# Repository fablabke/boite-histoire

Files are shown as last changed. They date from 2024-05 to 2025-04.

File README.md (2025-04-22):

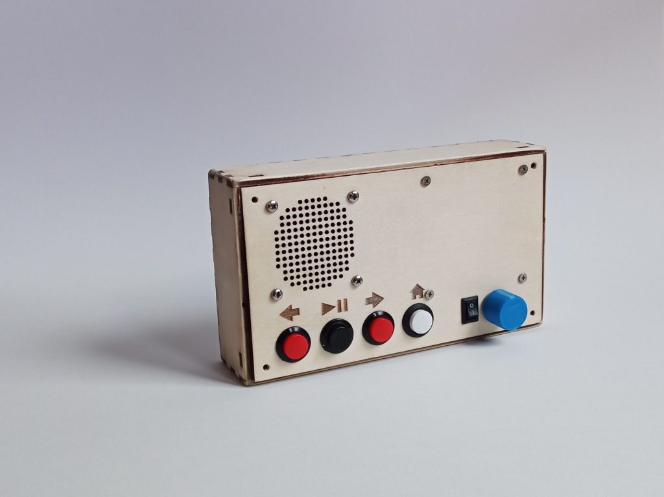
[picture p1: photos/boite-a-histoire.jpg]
Une boite à histoire open hardware


## Boite à histoire

Une boite à histoire complètement open source et open hardware, un projet du Fablab'ke.

Il existe sur le marché une série de “boîtes à histoires” qui permettent aux enfants d’écouter des histoires en audio. C’est un système qui fonctionne très bien et permet d’éviter les écrans tout en découvrant des univers assez variés. Écouter des histoires permet aussi de développer le langage et l’imaginaire.

Il y a par exemple la [boîte Lunii](https://lunii.com/fr-be/) et [pleins d’autres modèles](https://www.madmoizelle.com/quelles-sont-les-meilleures-boites-a-histoires-pour-les-enfants-1392363)

L’inconvénient majeur de toutes ces boîtes est le coût élevé de l’appareil (entre 70 et 100 euros) et le coût des packs d’histoires (une dizaine d’euros à chaque fois que l’on veut ajouter quelques histoires sur sa boîte sans pouvoir les partager avec d’autres).

Un autre inconvénient est que les bibliothèques d’histoires sont spécifiques à chaque fabricant, avec un contenu souvent assez lisse et peu multiculturel.

Nous avons décidé au Fablab'ke de développer et de fabriquer “notre” boîte à histoire maison, de créer en partenariat avec les autres cellules de la maison des cultures plusieurs projets autour de celle-ci, et d’en faire bénéficier les familles de la maison des cultures et au-delà.

Cette boite à histoire permet d'y installer autant d'histoire qu'on le souhaite, sans devoir passer par un "app-store" et permet du coup d'inventer et de se partager des histoires entre participant.e.s.

Une première série de 30 boites à histoire a été construite avec les classes d'informatique de Campus Saint Jean.

Ce projet est en cours de conception. [Contactez le fablab'ke](https://fablabke.be) pour plus d'informations.

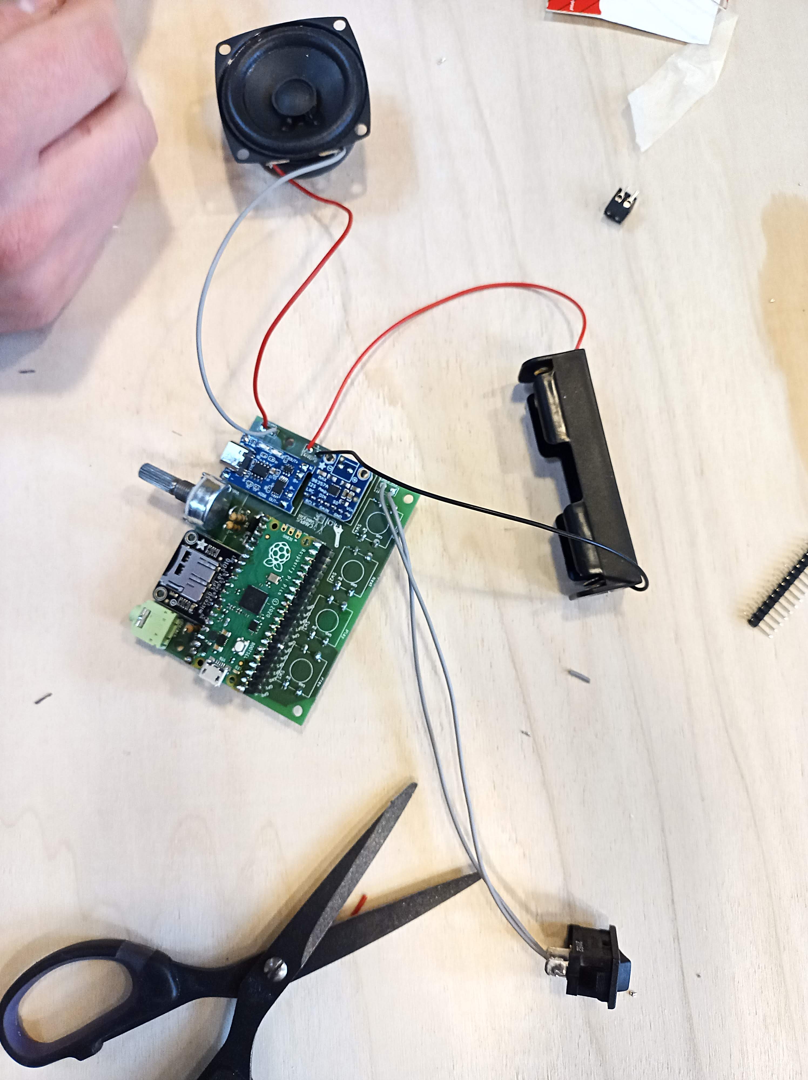
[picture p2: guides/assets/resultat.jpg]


## Mais comment fabriquer sa boite à histoire?

Lisez les documents suivants afin de comprendre les différentes étapes de fabrication et comment fabriquer la vôtre : 

- Principe de fonctionnement (todo)
- Carte électronique chez Aisler (todo)
- [Assemblage de la carte électronique](./guides/pcb.md)
- Code source arduino, facilement compilable avec platformio ou l'ide arduino : [/dossier arduino](./arduino)
- Code circuitpython (todo)

## Liste des composants nécessaires
- une plaquette d'expérimentation ou le circuit imprimé que l'on peut commander en ligne chez aisler.
- carte raspberry pi pico
- carte ampli i2s adafruit https://www.adafruit.com/product/3006 (clone : https://www.aliexpress.com/item/1005005985389931.html )
- carte chargeur (si vous voulez connecter une batterie) https://www.aliexpress.com/item/1005005982385924.html
- carte breakout sd adafruit : https://www.adafruit.com/product/4682
- potentiometre à souder trough hole 10k (par exemple : https://www.mouser.fr/ProductDetail/Same-Sky/PTN16-A10220K1B1?qs=VJzv269c%252BPbZP2voFoR5Tw%3D%3D )
- prise jack pour casque de ce type : https://www.mouser.be/ProductDetail/Same-Sky/SJ1-3525NG-GR?qs=WyjlAZoYn51BeLQaUbXH3w%3D%3D
- 3 résistances de 100k

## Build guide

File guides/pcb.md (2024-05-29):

# Assemblage de la boite à histoire

Matériel nécessaire :

- fer à souder
- soudure
- pince à dénuder
- pince coupante
- des ciseaux
- du scotch de peintre

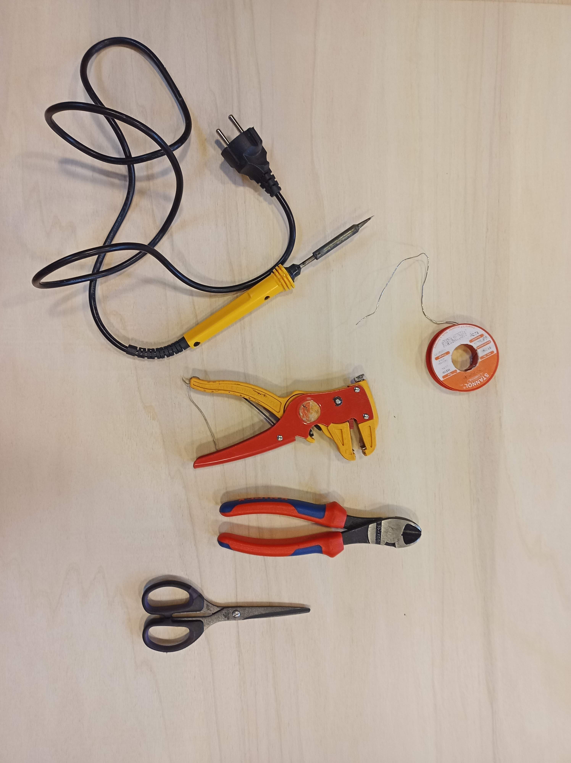
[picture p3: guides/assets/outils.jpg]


On commence par les composants passifs (diodes et résistances)

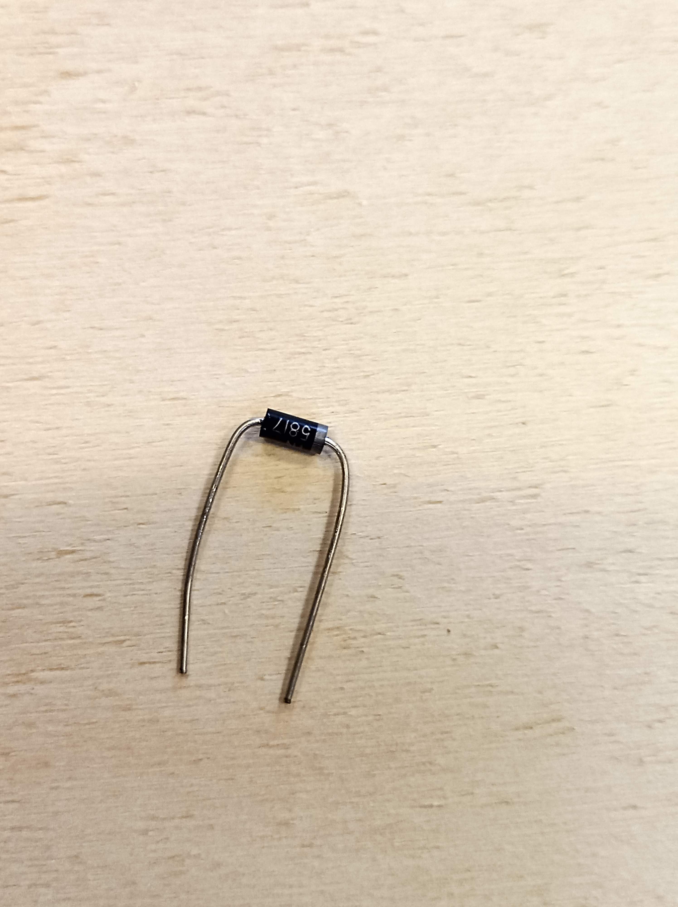
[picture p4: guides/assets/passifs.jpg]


Plier les pates de résistances et des diodes :

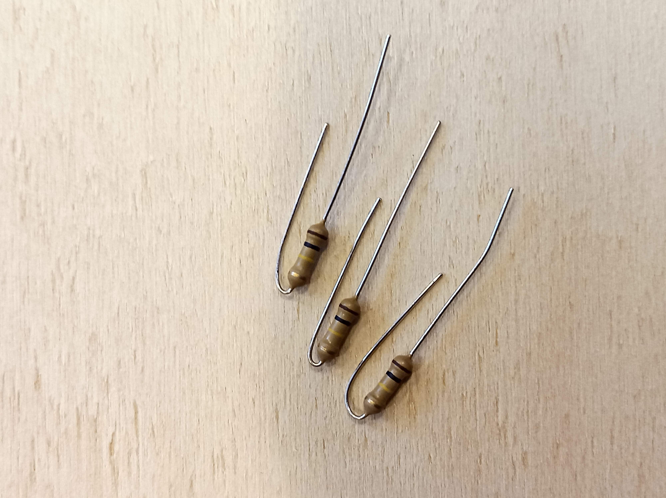
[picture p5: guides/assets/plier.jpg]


Placer la diode et les résistances sur le circuit imprimé (PCB). On peut plier les pates pour que les composants ne bougent pas.

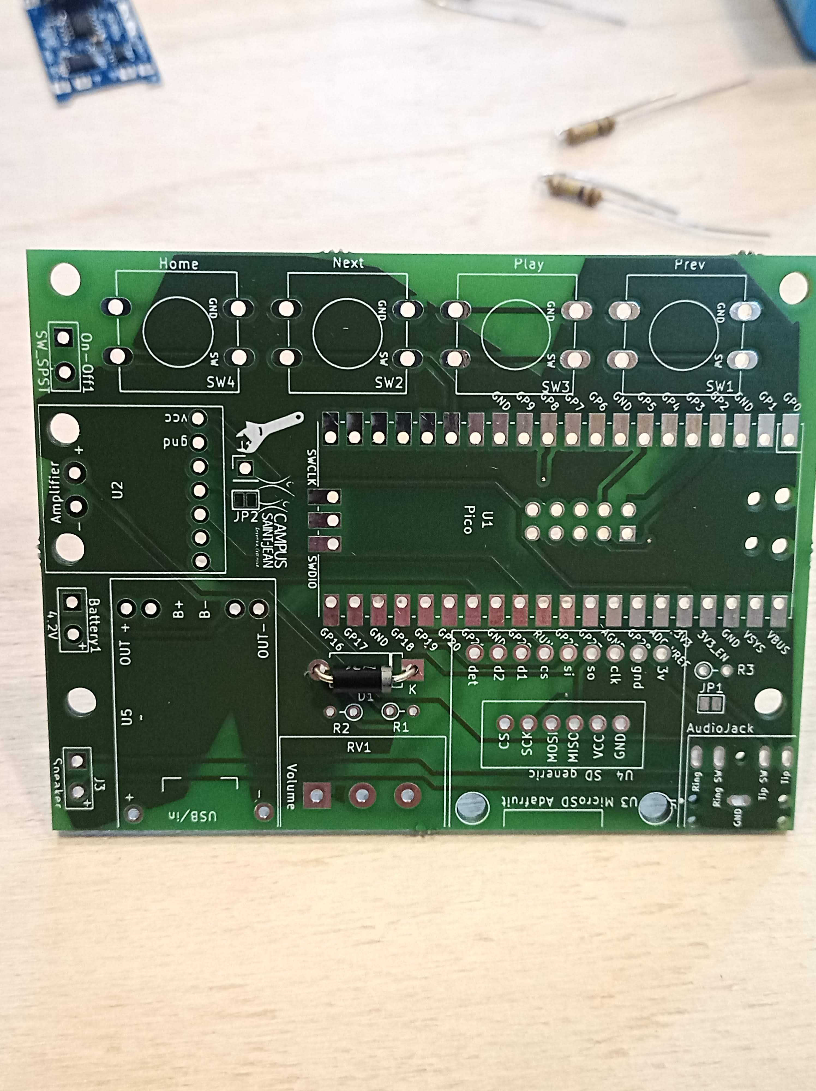
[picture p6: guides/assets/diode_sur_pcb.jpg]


Souder les pates :
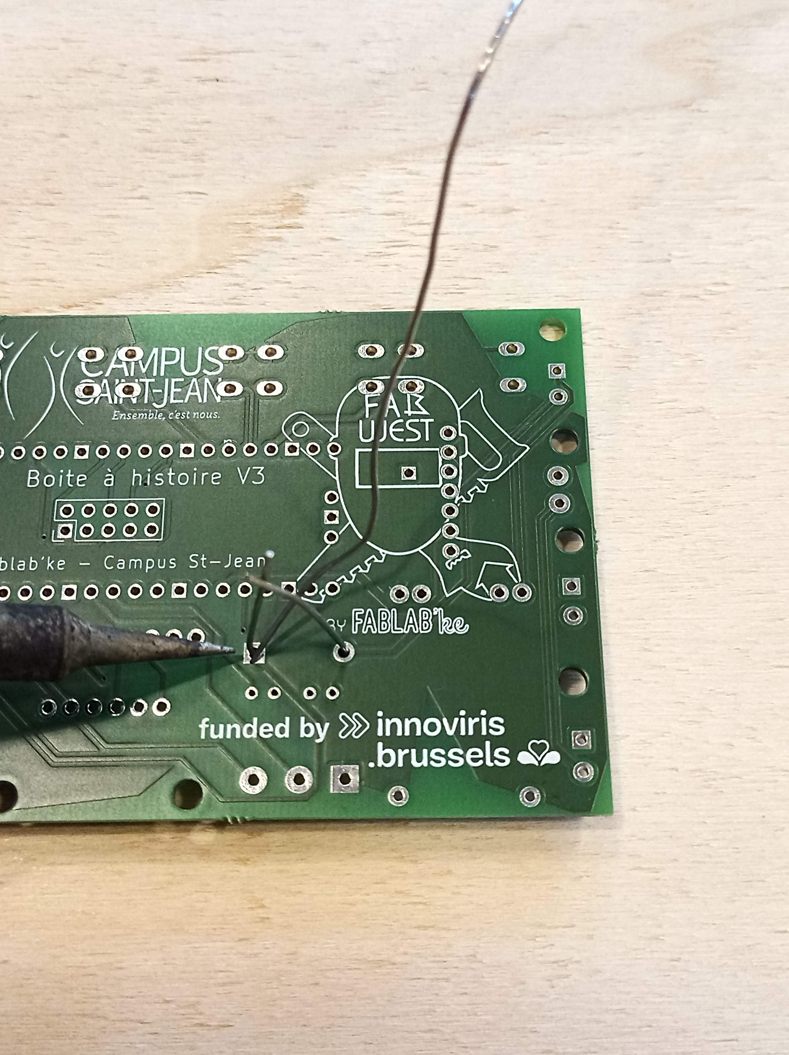
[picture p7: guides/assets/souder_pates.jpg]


On passe au lecteur de cartes SD : 
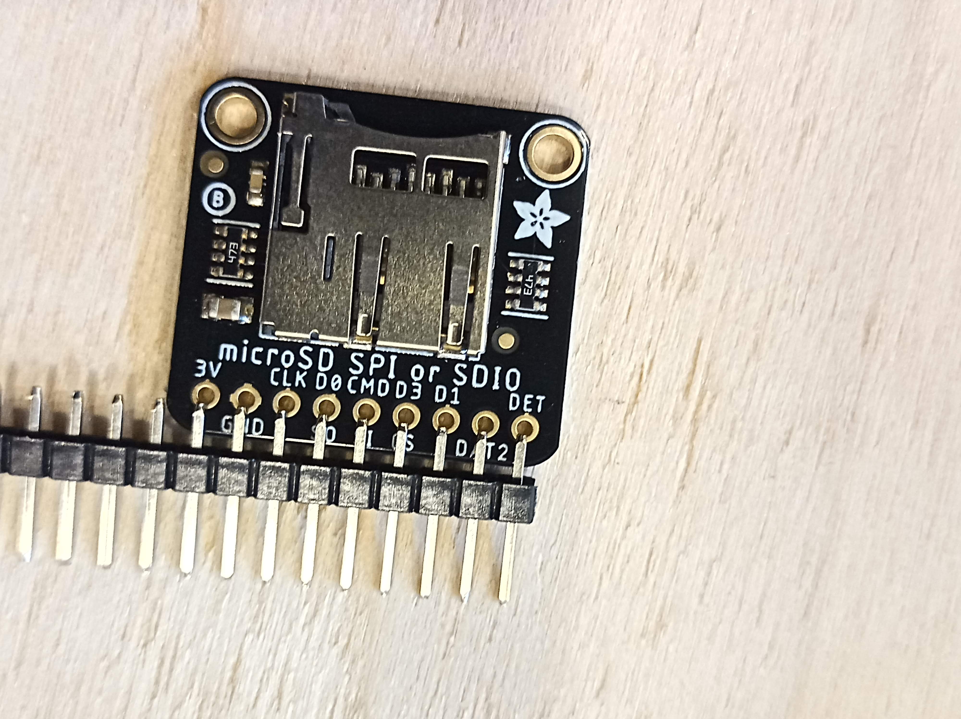
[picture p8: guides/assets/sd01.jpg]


Découper la barette de pins à la bonne longueur :
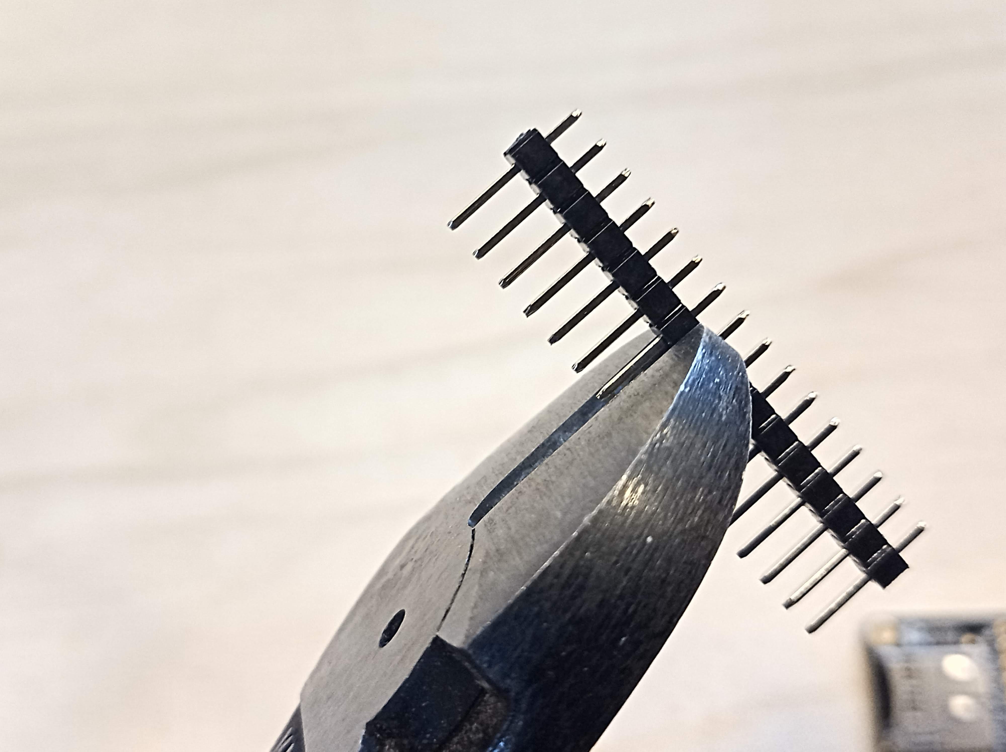
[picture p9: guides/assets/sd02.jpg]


Assembler le lecteur de carte et la barette. Placer le tout sur le circuit imprimé.
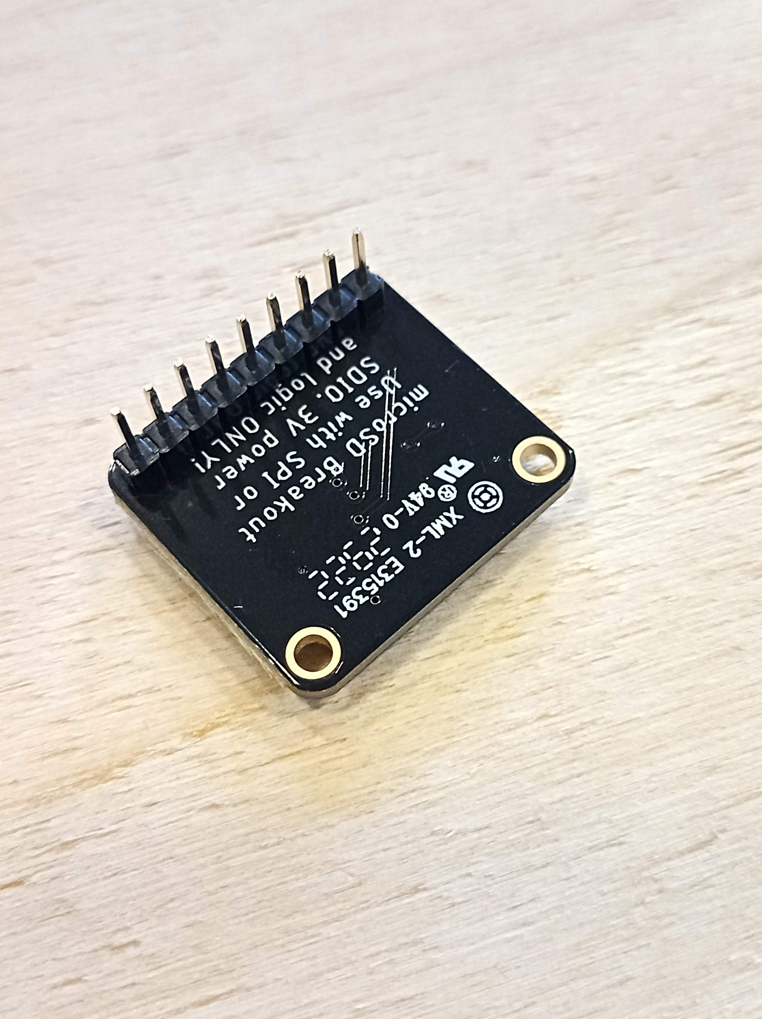
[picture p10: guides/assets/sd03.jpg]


Attention à garder le lecteur de carte SD bien droit, bien parallèle au circuit imprimé. On peut s'aider d'une ptite calle avant de souder.
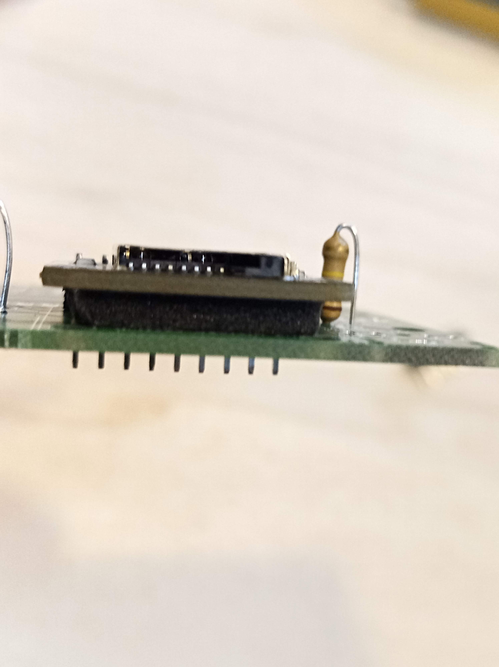
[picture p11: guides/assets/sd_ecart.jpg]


Souder les broches côté lecteur de carte SD et ensuite à l'arrière du circuit imprimé
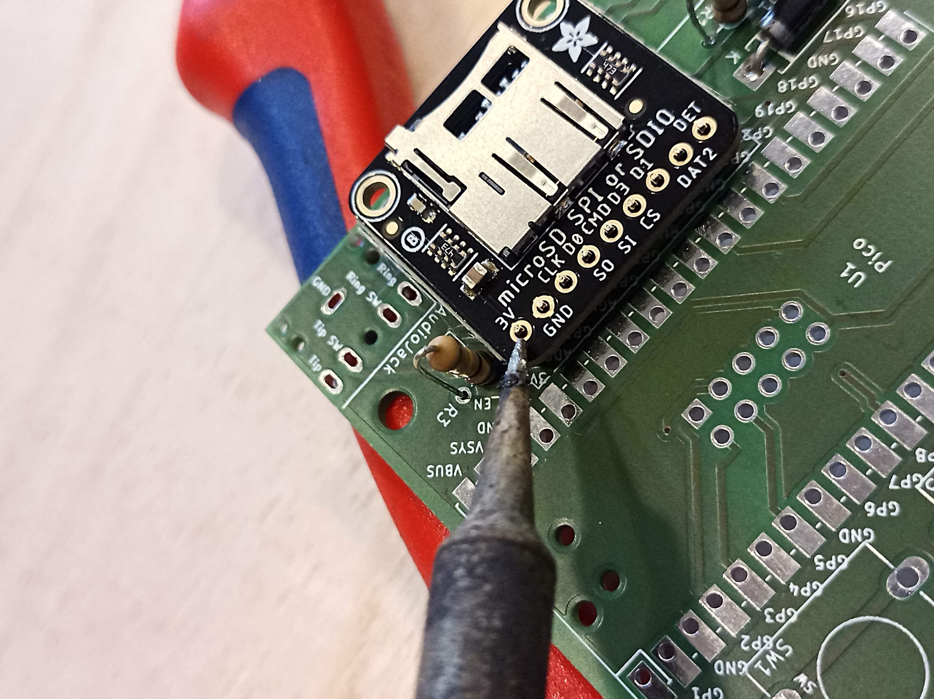
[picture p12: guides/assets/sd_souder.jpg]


On continue avec la carte son, couper les broches nécessaires :
- 1x 7 broches
- 2x 1 broche

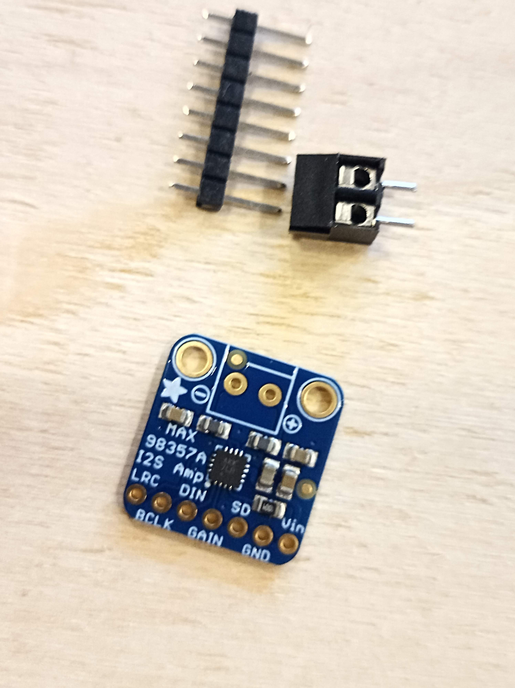
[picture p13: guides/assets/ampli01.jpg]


Ensuite mettre les broches à l'arrière de la carte ampli et insérer le tout sur le PCB
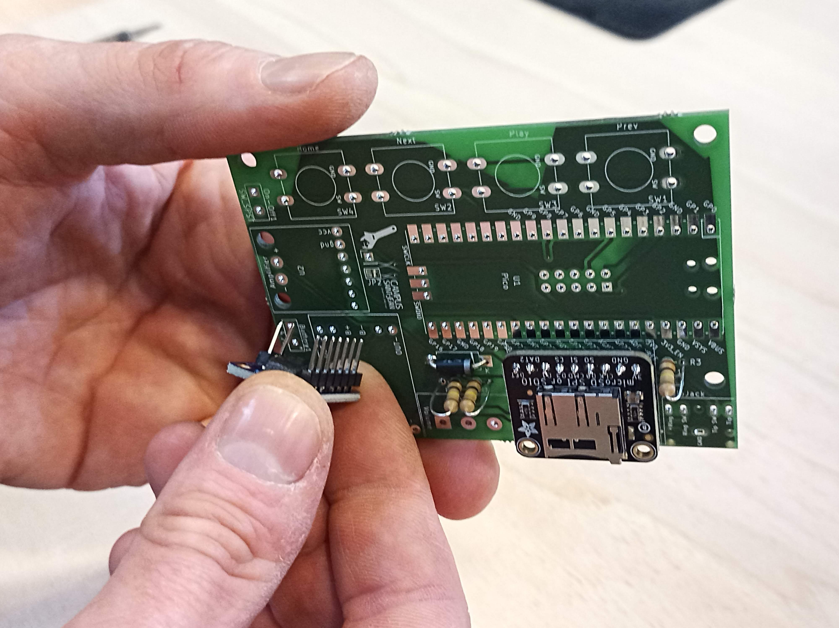
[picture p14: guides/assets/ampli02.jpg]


Un morcau de scotch permet de maintenir la carte avant de la souder :
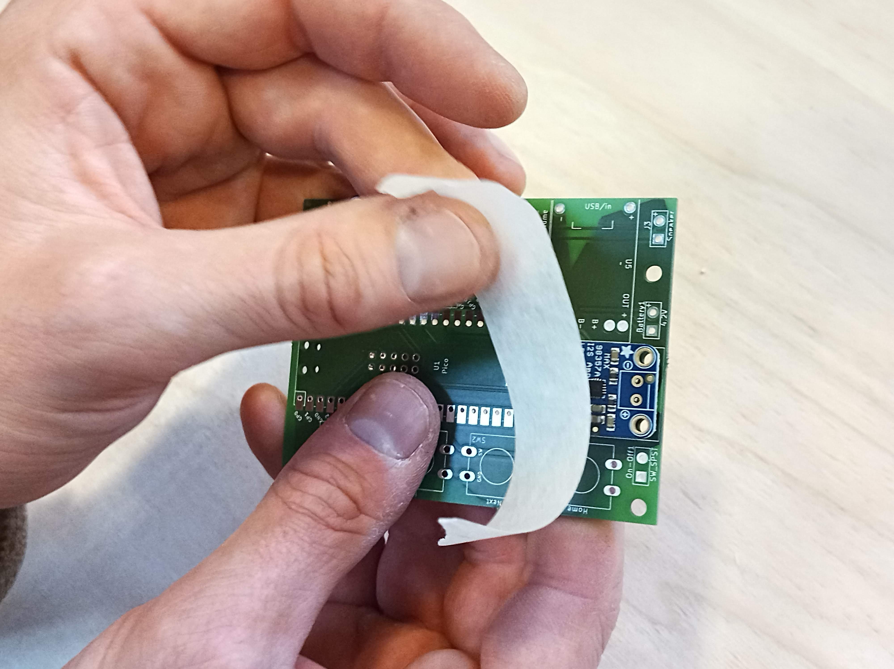
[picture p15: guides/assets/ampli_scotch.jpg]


On continue avec le chargeur, il faut couper 2x 2 pins et 2x 1 pin, tout mettre sur la PCB et ensuite positionner le chargeur sur les pins et souder le tout. 
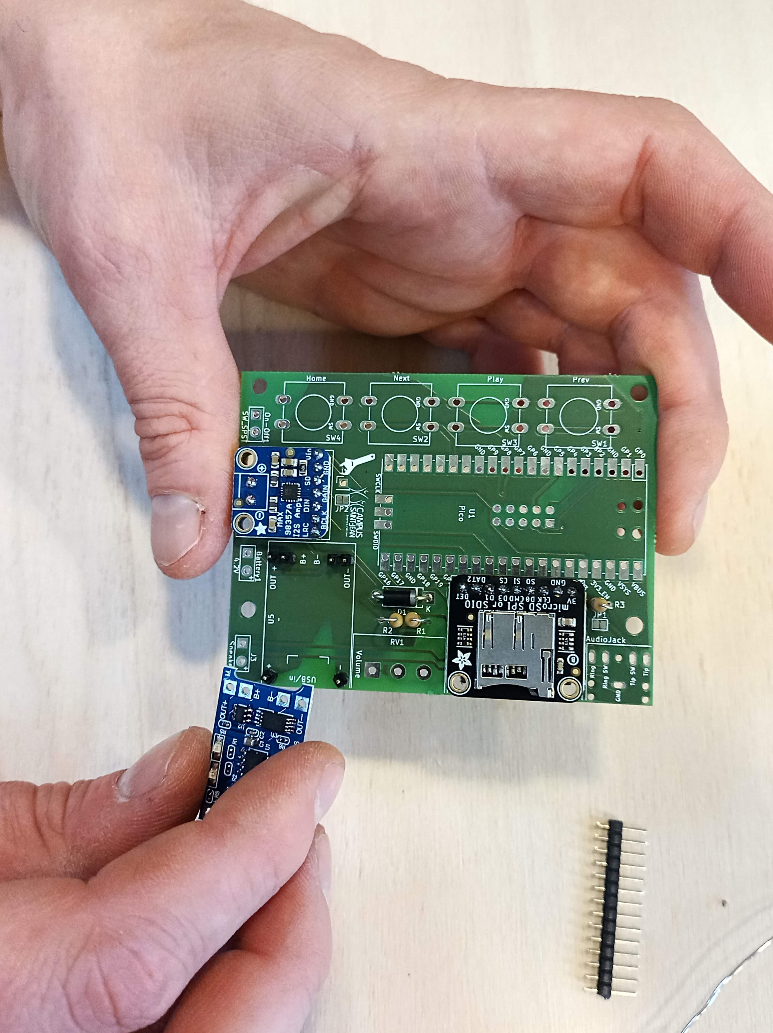
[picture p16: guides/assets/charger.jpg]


Veillez a bien garder le chargeur parallèlle au PCB
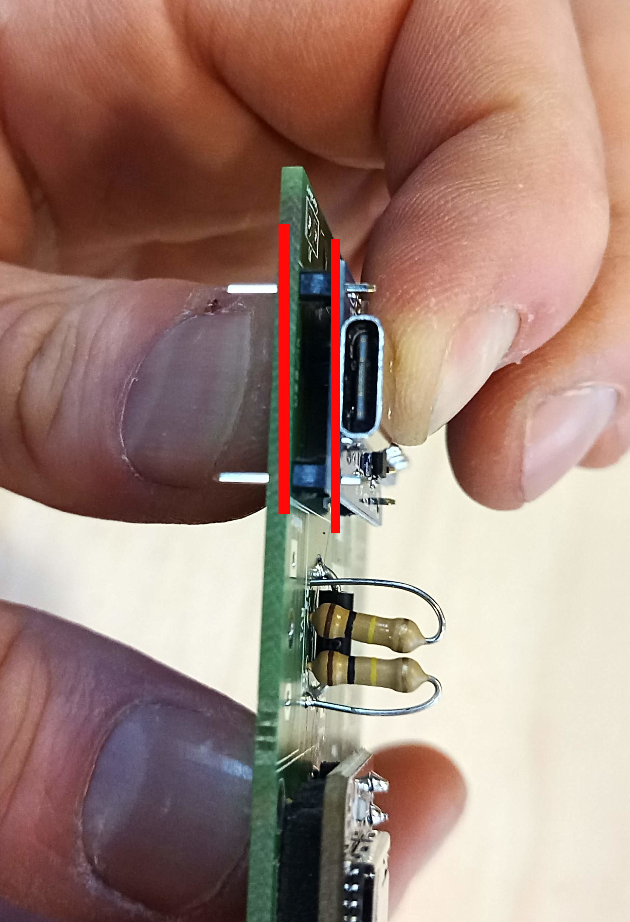
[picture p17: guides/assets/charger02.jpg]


Un sctoch est de nouveau bien pratique pour maintenir le tout.
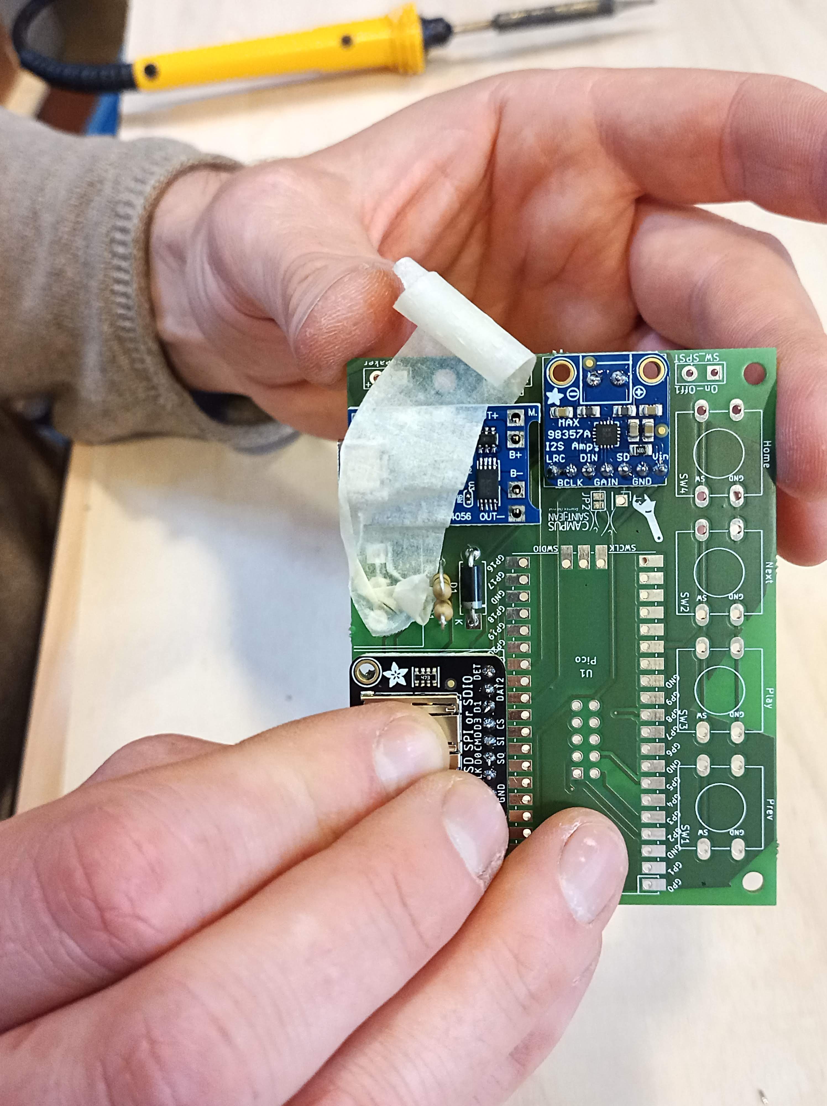
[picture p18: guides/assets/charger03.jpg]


Prendre la pico et enfoncer le "header" sur ses broches :
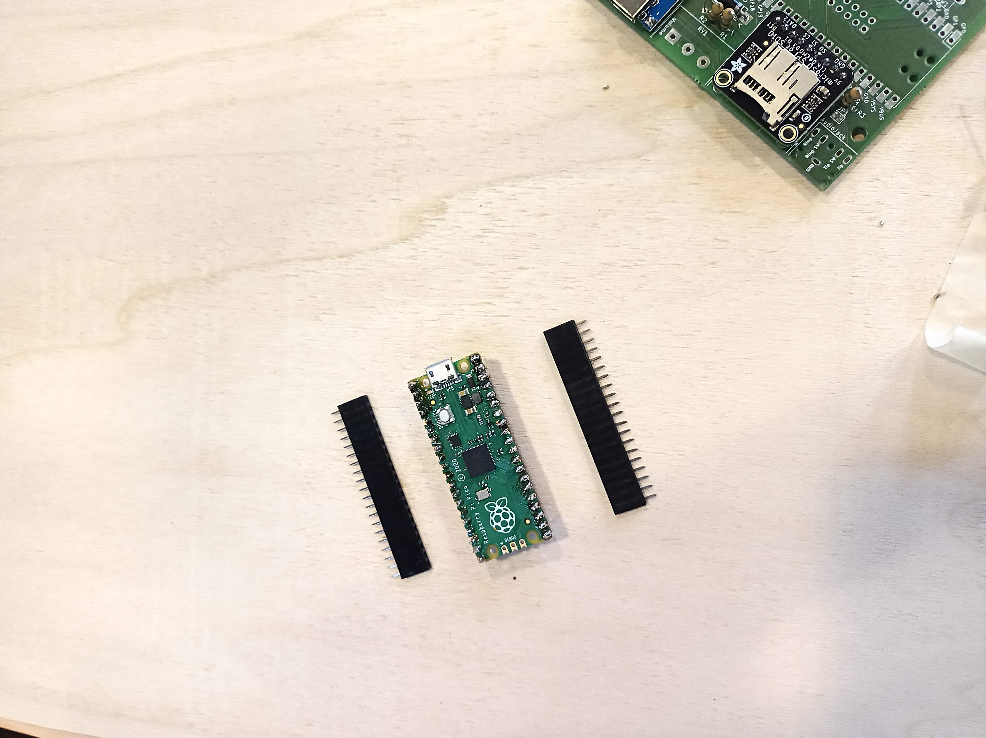
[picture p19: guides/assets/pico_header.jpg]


Placer la carte pico avec ces header et souder les broches
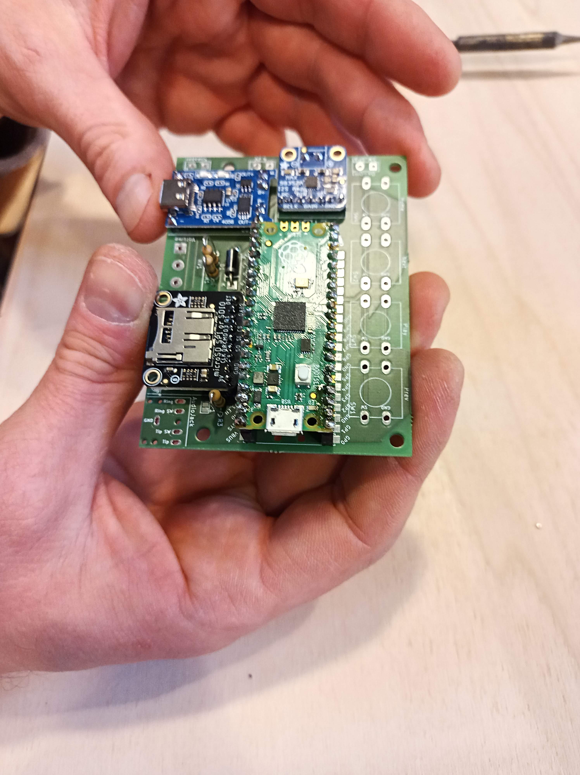
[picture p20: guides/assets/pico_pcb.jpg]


Encore une fois, le scotch permet de tout bien maintenir :-)
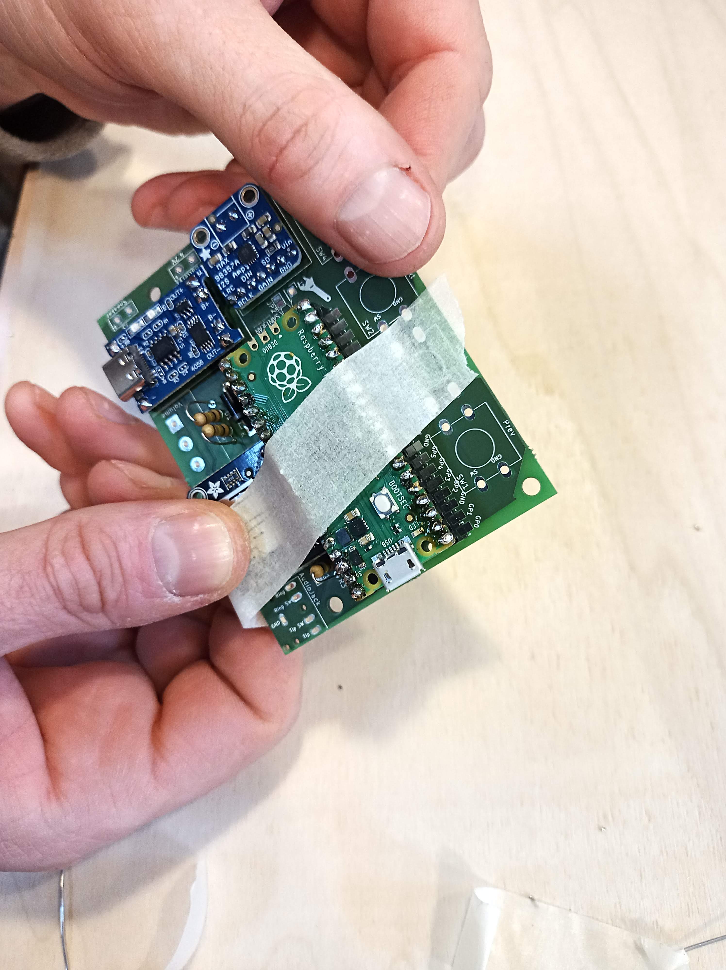
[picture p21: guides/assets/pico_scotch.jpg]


Souder chaque broche en faisant attention à ne pas créer de pont entre deux soudures
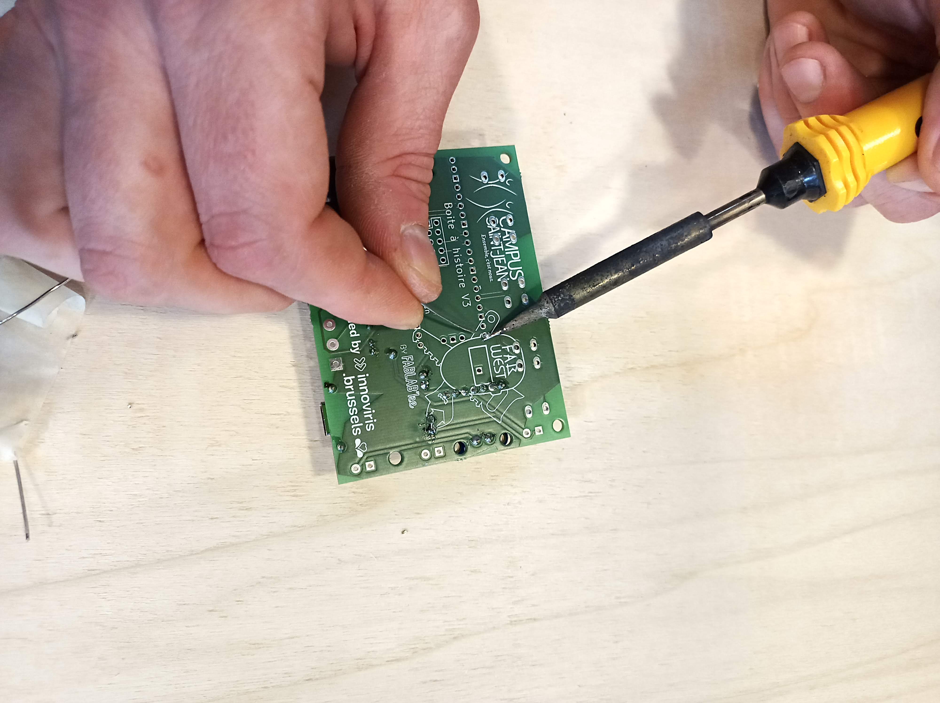
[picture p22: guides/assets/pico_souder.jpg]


On passe aux switches, soit souder le switches directement sur la pcb, soit souder des fils de cablage pour avoir des switchs déportés sur le boitier
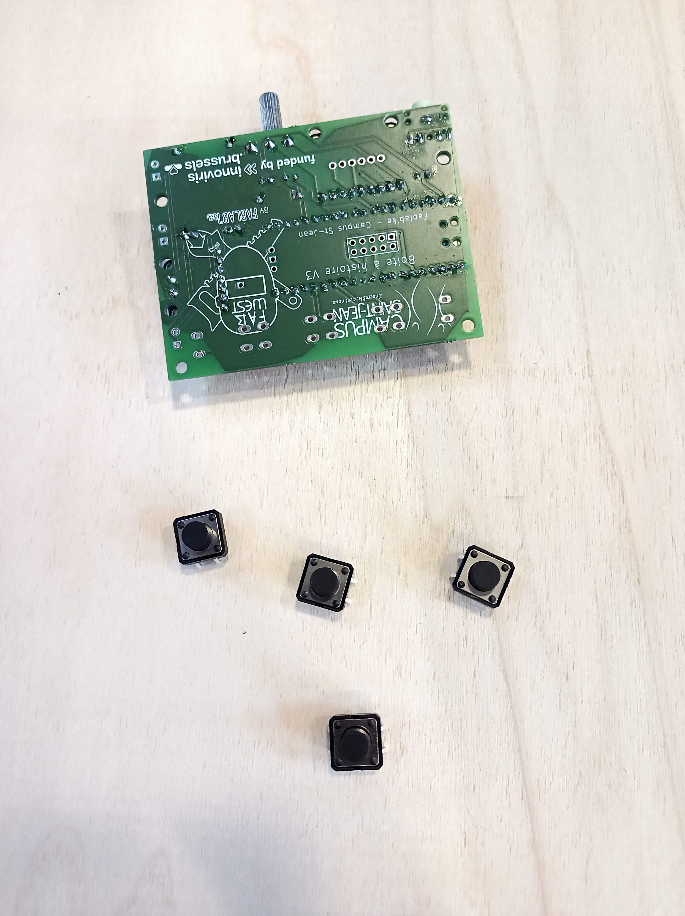
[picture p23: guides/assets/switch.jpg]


Exemple ici avec les switch soudés à l'arrière de la PCB. La carte sera vissée directement au boitier afin que les switches soient visibles.
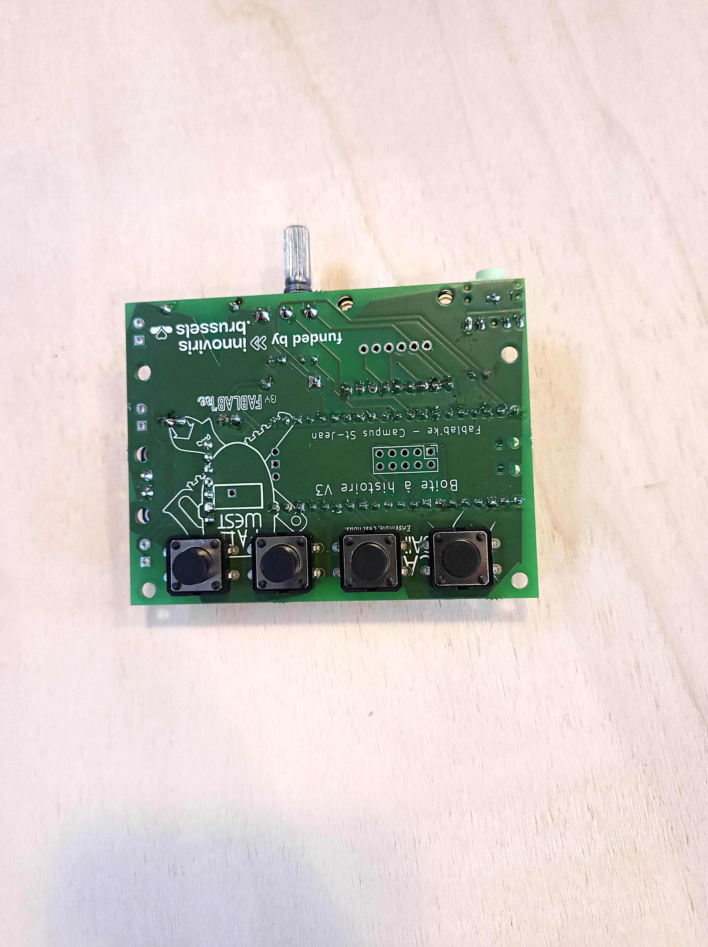
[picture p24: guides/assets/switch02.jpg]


Souder le potentiomètre directement sur la PCB
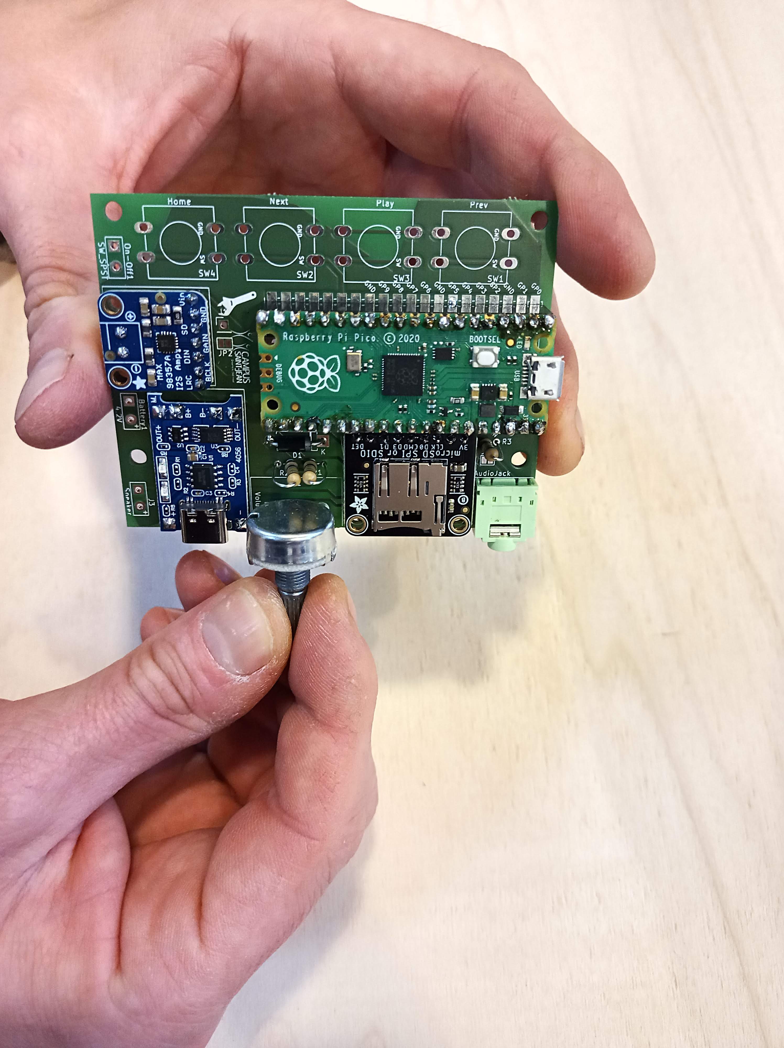
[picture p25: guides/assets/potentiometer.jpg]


Terminer par souder du fil de cablage sur les pads "switch", "speaker", en s'aidant d'un scotch
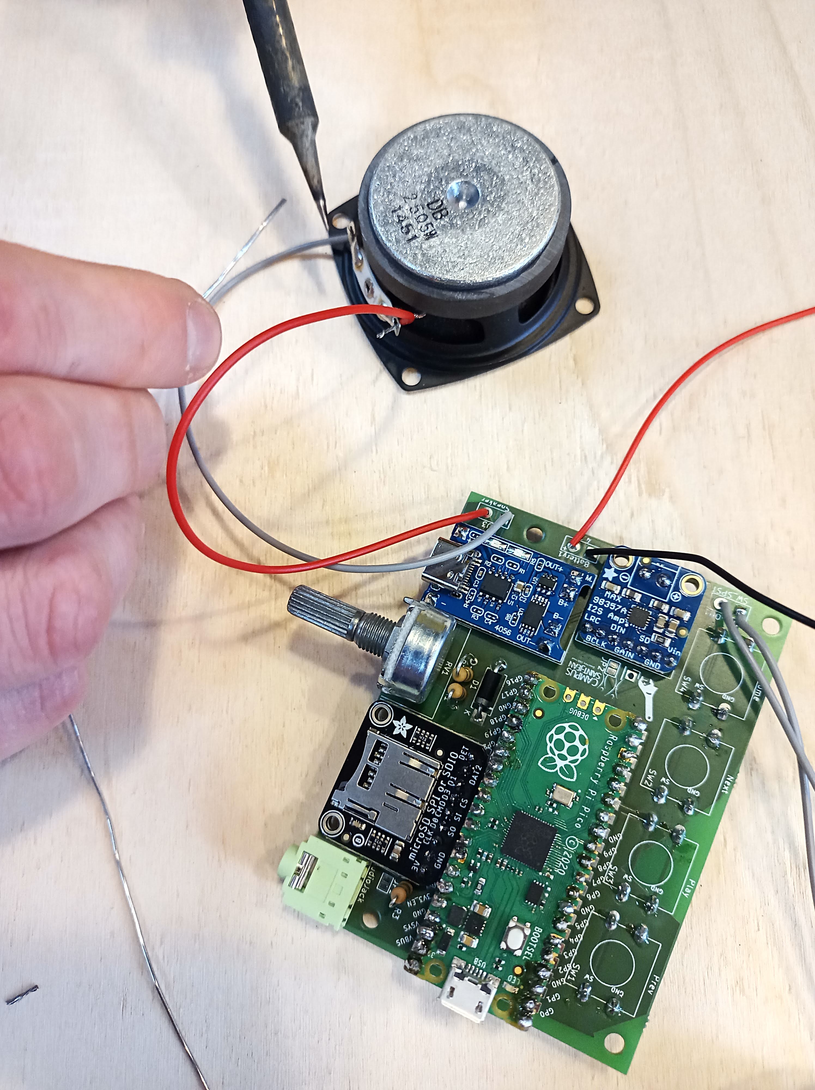
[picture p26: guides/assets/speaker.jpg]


Et voilà, tout est soudé :






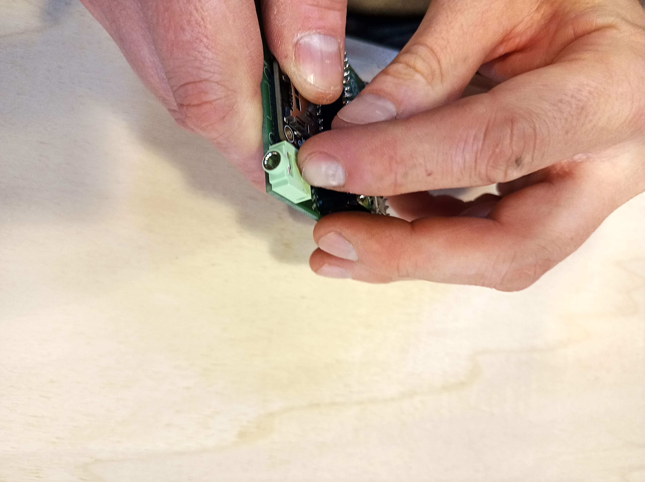
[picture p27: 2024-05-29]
guides/assets/jack.jpg

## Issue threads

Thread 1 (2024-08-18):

Schémas électriques

nonobike, 2024-08-18:
Bonjour,

D'abord merci beaucoup pour votre travail qu'il est remarquable.

Avez vous le schéma de cablage complet du projet ?

Je n'ai rien trouvé dans le github

Merci

Arnaud

philippejadin, 2024-08-19:
Merci!
Je viens d'ajouter le shéma en version pdf ici : https://github.com/fablabke/boite-histoire/blob/main/pcb/storybox.pdf

Si vous installez kicad, vous pourrez voir le schemé ainsi que la PCB.

philippejadin, 2024-08-19:
Et ça nous fera super plaisir d'avoir des retours, ici ou par mail :-)
Je compte encore travailler à ce projet afin de le rendre fabriquable par d'autres sans trop de difficultés.

brunodeprez, 2025-01-03:
Super interessé par ce projet !

philippejadin, 2025-01-03:
N'hésitez si vous avez des questions. Je dois encore un peu retravailler le firmware mais à part ça le projet est très fonctionnel

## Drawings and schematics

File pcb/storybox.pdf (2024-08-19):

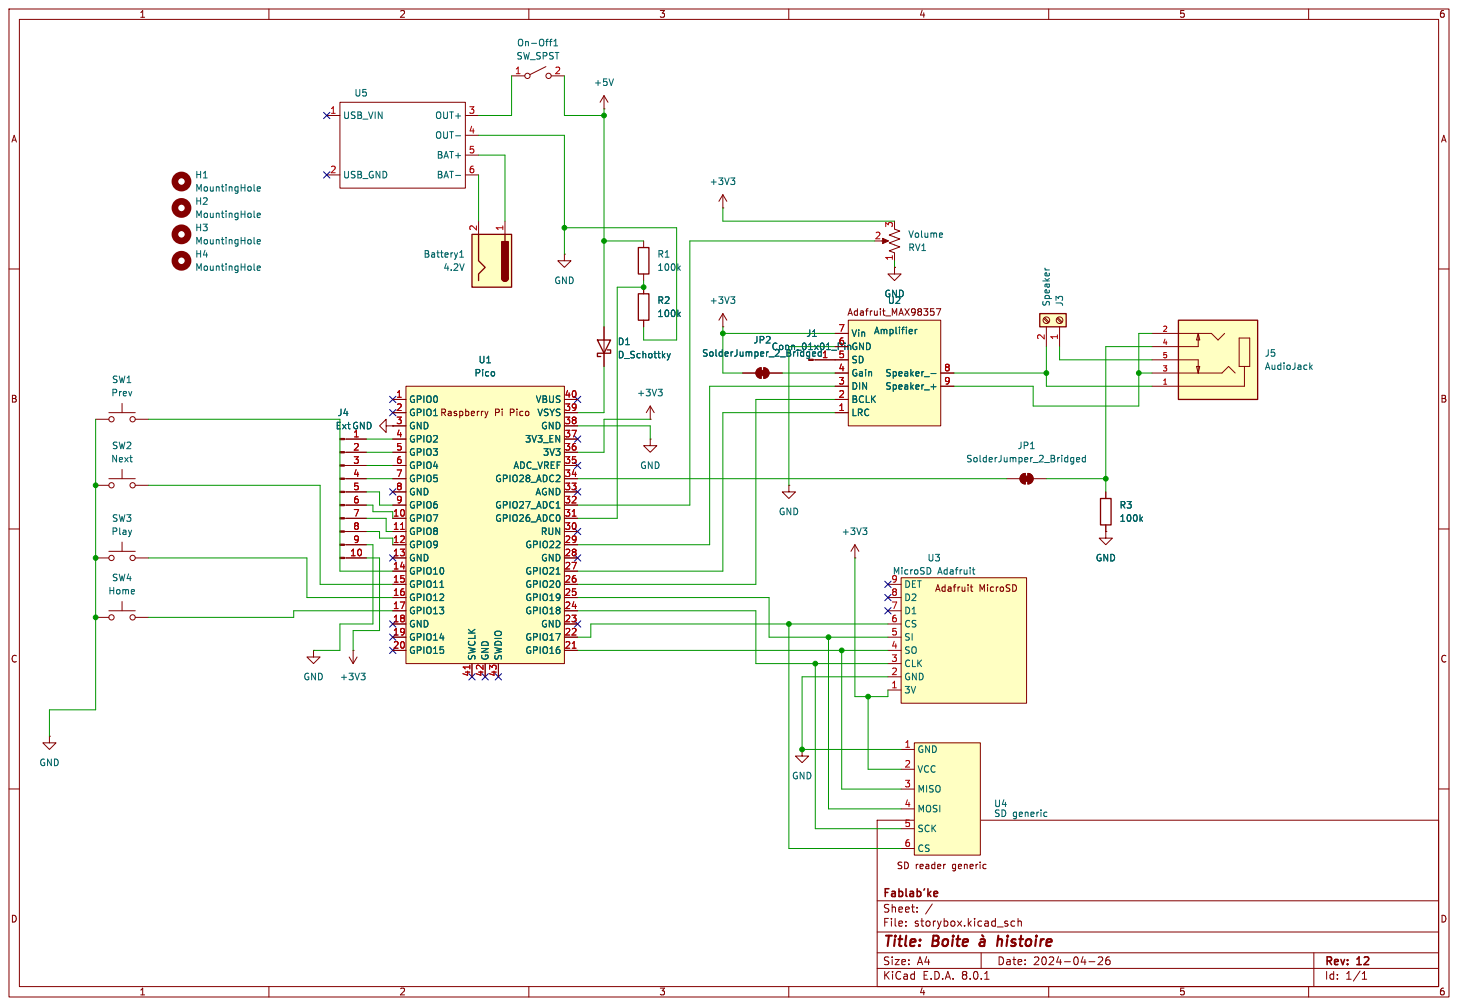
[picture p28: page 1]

File: storybox.kicad_sch Sheet: / Fablab'ke GND

Id: 1/1 Title: Boite þÿàhistoire

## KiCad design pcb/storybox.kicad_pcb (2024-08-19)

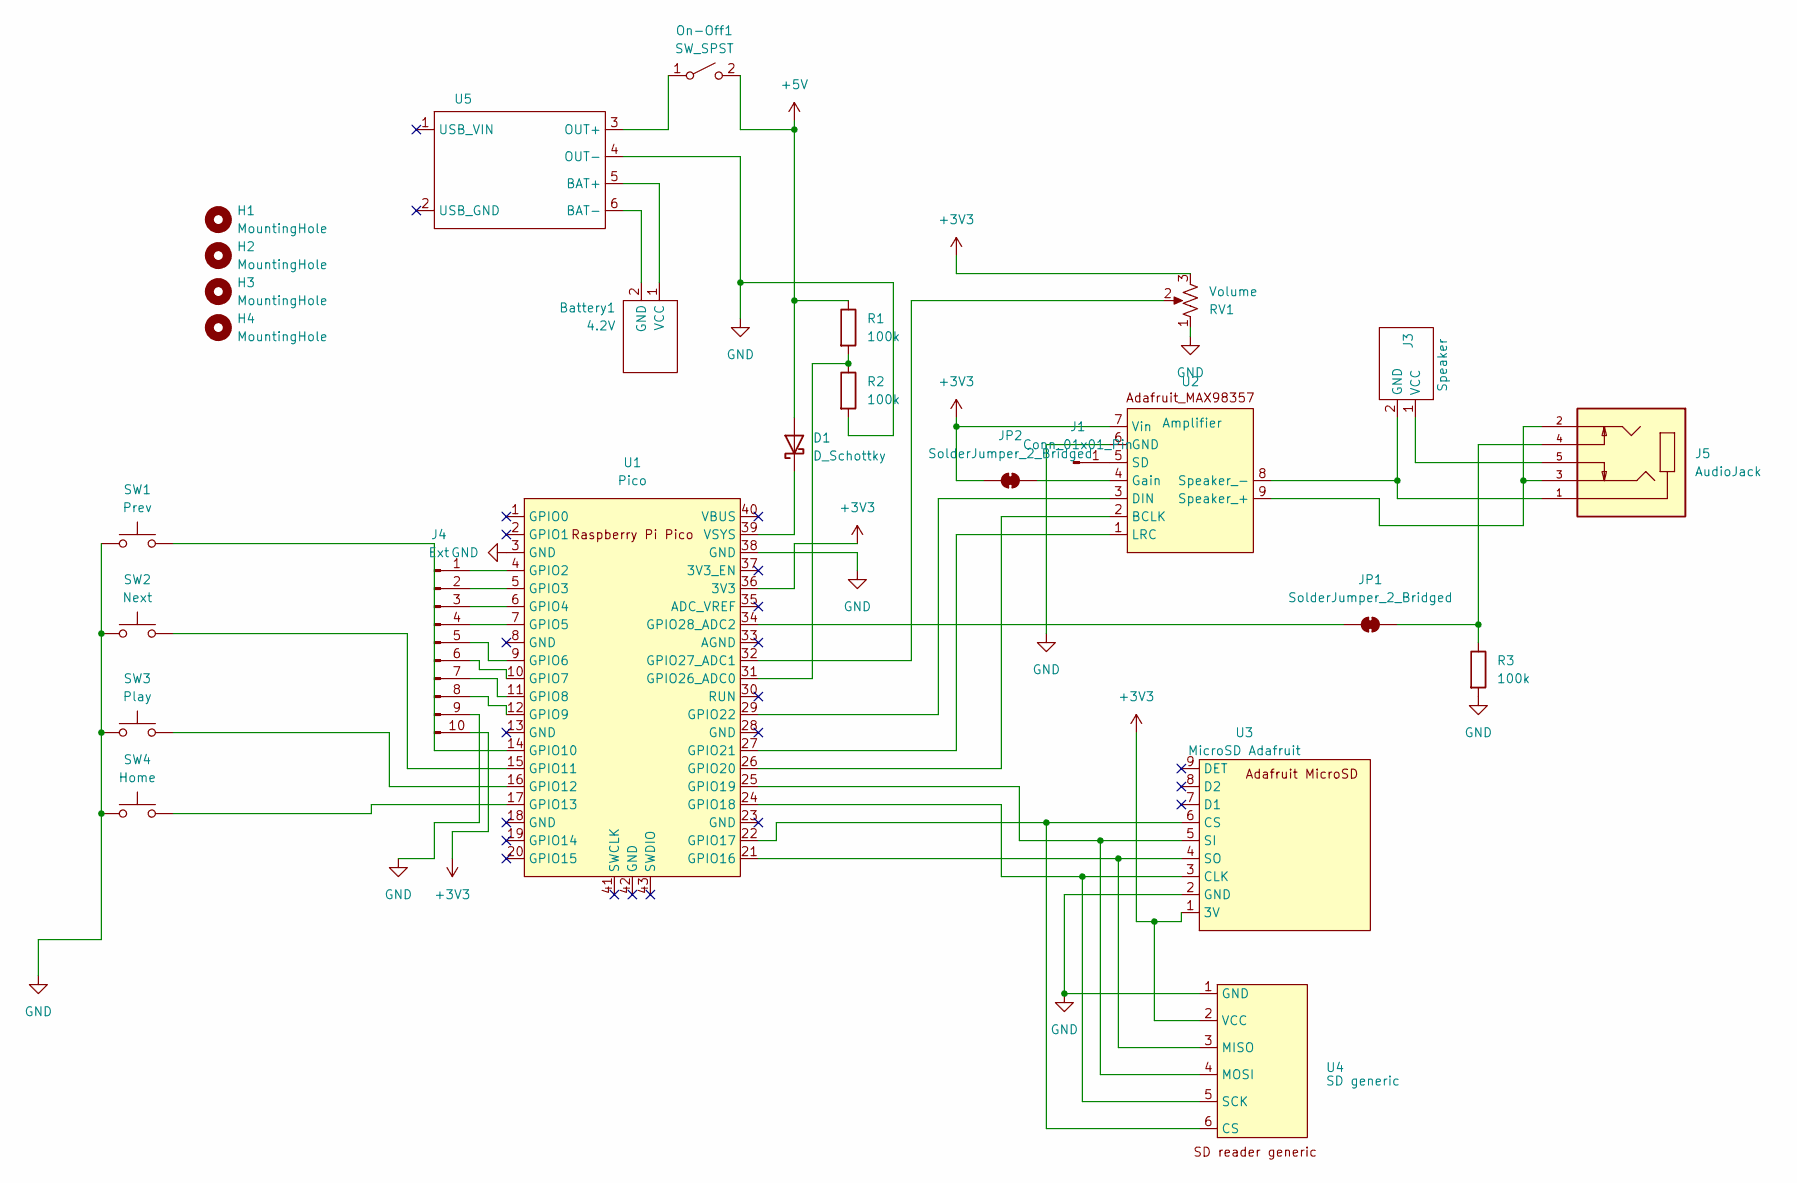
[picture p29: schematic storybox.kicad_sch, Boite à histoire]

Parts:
Battery1: 4.2V; connector_polarized
D1: D_Schottky; D_DO-15_P10.16mm_Horizontal
H1, H2, H3, H4: MountingHole; MountingHole_3.2mm_M3
J1: Conn_01x01_Pin; PinHeader_1x01_P2.54mm_Vertical
J3: Speaker; connector_polarized
J4: Ext; PinHeader_2x05_P2.54mm_Vertical
J5: AudioJack; CUI_SJ1-3525NG-GR
JP1, JP2: SolderJumper_2_Bridged; SolderJumper-2_P1.3mm_Bridged_Pad1.0x1.5mm
On-Off1: SW_SPST; connector_polarized
R1, R2, R3: 100k; R_Axial_DIN0204_L3.6mm_D1.6mm_P2.54mm_Vertical
RV1: Volume; Potentiometer_Alps_RK163_Single_Horizontal
SW1: Prev; SW_PUSH-12mm
SW2: Next; SW_PUSH-12mm
SW3: Play; SW_PUSH-12mm
SW4: Home; SW_PUSH-12mm
U1: Pico; RPi_Pico_SMD_TH
U2: Amplifier; Adafruit_MAX98357
U3: MicroSD Adafruit; Adafruit_MicroSd_3v
U4: SD generic; sd_reader_generic
U5: tp4056

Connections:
+3V3: J4.10, JP2.1 (A), RV1.3, U1.36 (3V3), U2.7 (Vin), U3.1 (3V), U4.2 (VCC)
+5V: D1.2 (A), On-Off1.2 (B), R1.1
GND: J4.9, R2.2, R3.2, RV1.1, SW1.2, SW2.2, SW3.2, SW4.2, U1.3 (GND), U1.38 (GND), U2.6 (GND), U3.2 (GND), U4.1 (GND), U5.4 (OUT-)
unnamed: D1.1 (K), U1.39 (VSYS)
unnamed: J1.1, U2.5 (SD)
unnamed: J3.1, J5.5
unnamed: J3.2, J5.1, U2.8 (Speaker_-)
unnamed: J4.1, U1.4 (GPIO2)
unnamed: J4.2, U1.5 (GPIO3)
unnamed: J4.3, U1.6 (GPIO4)
unnamed: J4.4, U1.7 (GPIO5)
unnamed: J4.5, U1.9 (GPIO6)
unnamed: J4.6, U1.10 (GPIO7)
unnamed: J4.7, U1.11 (GPIO8)
unnamed: J4.8, U1.12 (GPIO9)
unnamed: JP1.1 (A), U1.34 (GPIO28_ADC2)
unnamed: J5.4, JP1.2 (B), R3.1
unnamed: JP2.2 (B), U2.4 (Gain)
unnamed: On-Off1.1 (A), U5.3 (OUT+)
unnamed: SW1.1, U1.14 (GPIO10)
unnamed: SW2.1, U1.15 (GPIO11)
unnamed: SW3.1, U1.16 (GPIO12)
unnamed: SW4.1, U1.17 (GPIO13)
unnamed: U1.21 (GPIO16), U3.4 (SO), U4.3 (MISO)
unnamed: U1.22 (GPIO17), U3.6 (CS), U4.6 (CS)
unnamed: U1.24 (GPIO18), U3.3 (CLK), U4.5 (SCK)
unnamed: U1.25 (GPIO19), U3.5 (SI), U4.4 (MOSI)
unnamed: U1.26 (GPIO20), U2.2 (BCLK)
unnamed: U1.27 (GPIO21), U2.1 (LRC)
unnamed: U1.29 (GPIO22), U2.3 (DIN)
unnamed: R1.2, R2.1, U1.31 (GPIO26_ADC0)
unnamed: RV1.2, U1.32 (GPIO27_ADC1)
unnamed: J5.2, J5.3, U2.9 (Speaker_+)
unnamed: Battery1.1 (VCC), U5.5 (BAT+)
unnamed: Battery1.2 (GND), U5.6 (BAT-)

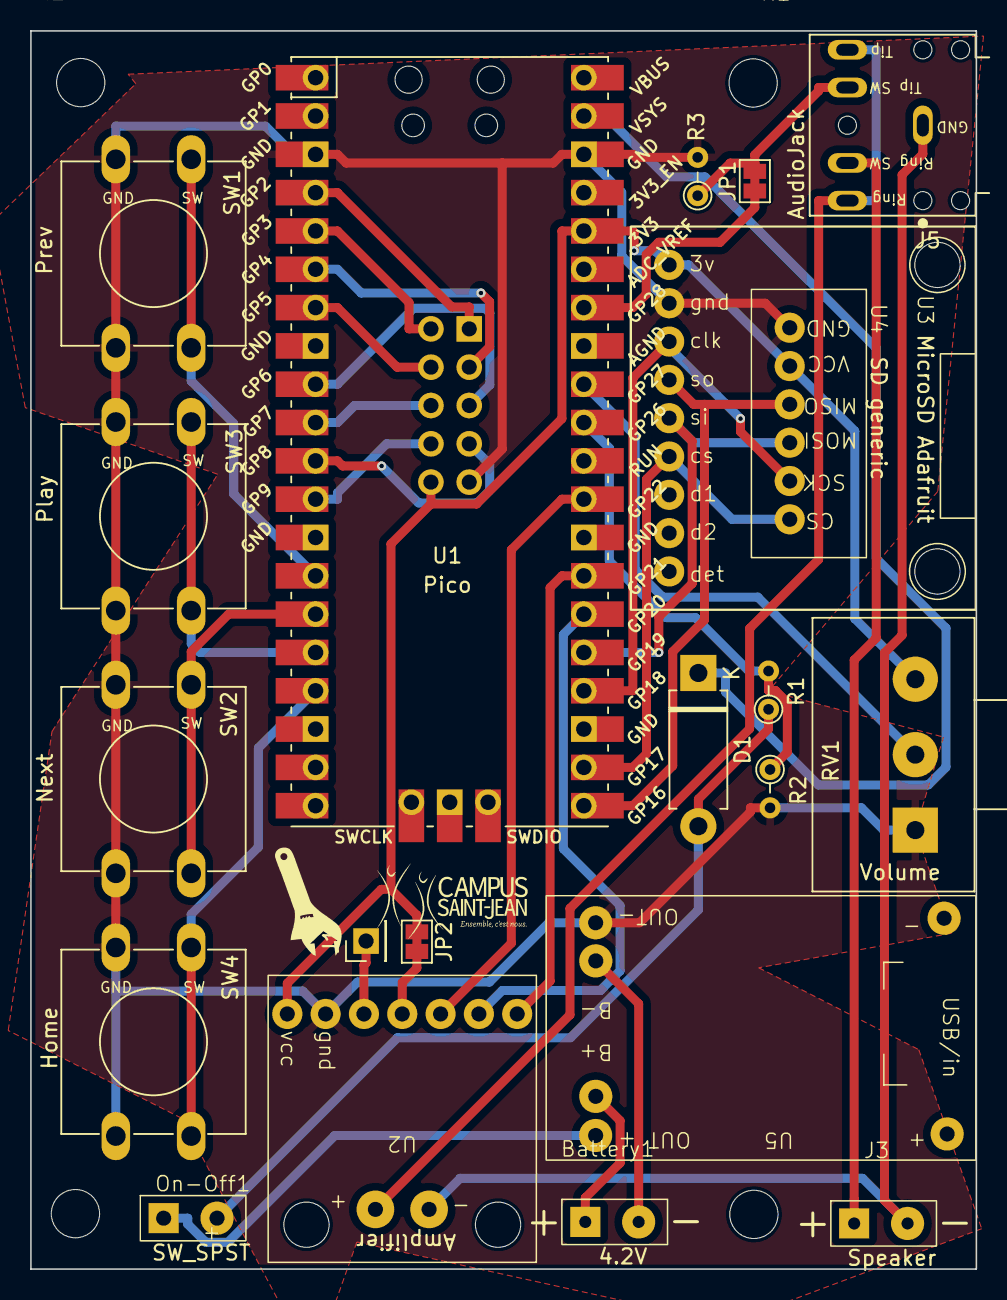
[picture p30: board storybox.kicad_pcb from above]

Board: 2 copper layers, 62.7 x 82.1 mm, 26 parts (1 on the bottom side), 35 nets.

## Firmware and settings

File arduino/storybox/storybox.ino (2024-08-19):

/**
Story box

Code pour la boite à histoire, version arduino.

Librairies utilisées :
https://github.com/LennartHennigs/Button2 (latest) // simple button handler
https://github.com/pschatzmann/arduino-audio-tools (latest)
https://github.com/pschatzmann/arduino-libhelix (latest)
https://github.com/jonnieZG/EWMA // smooth analog values (for smooth volume opperations)

à tester  : https://github.com/jonnieZG/EButton

 */

#include <SPI.h>
#include <SDFS.h>
#include "AudioTools.h"
#include "AudioCodecs/CodecMP3Helix.h"
#include "Button2.h"
#include <Ewma.h>

/***************** CONFIG *******************/

// max number of stories in a directory
#define MAXSTORIES 50

// max volume levels for speaker and headphones
#define MAX_SPEAKER_VOLUME 1000  // 0 -> 1024 // boost > 1024
#define MAX_HEADPHONE_VOLUME 400 // 0 -> 1024

#define JACK_DETECTION_LEVEL 800 // bellow this value it will be considered speaker, above jack

#define VOLUME_STEPS 16 // How many steps there are in the volume control (max 1024)

#define DEBUG true

#define VOLTAGE_DROP 0.4         // schotky diode voltage drop in volts
#define VOLTAGE_DIVIDER_FACTOR 2 // voltage divider using two resistors, must be adjusted
#define LOW_VOLTAGE_WARNING 2.8  // (volts) measured battery level bellow that will trigger the playback of the lowbattery.mp3 file on startup

/****************** no more config below vvvv **************/

/********************** HARDWARE PINS *************************/
#define SDCARD_SPI SPI
#define SDCARD_CS_PIN 17

#define BUTTON_LEFT_PIN 10
#define BUTTON_RIGHT_PIN 11
#define BUTTON_PLAY_PIN 12
#define BUTTON_HOME_PIN 13

#define I2S_BCK 20
#define I2S_WS 21
#define I2S_DATA 22

#define BATTERY_ADC_PIN 26
#define VOLUME_PIN 27
#define JACK_PIN 28

// #define BTN_DEBOUNCE_MS 100
#define COPIER_BUFFER_SIZE 512

#define HEADPHONE 0
#define SPEAKER 1

const int is_menu = 0;
const int is_play = 1;
const int is_pause = 2;

// #define SPI_CLOCK SD_SCK_MHZ(2)
// #define MP3_MAX_OUTPUT_SIZE 1024
// #define MP3_MAX_FRAME_SIZE 800

// #define MP3_MAX_OUTPUT_SIZE 1024 * 5 // 1024 * 5
// #define MP3_MAX_FRAME_SIZE 3200      // 1600
// #define I2S_BUFFER_SIZE 1024

/* end hardware config */

I2SStream i2s;
VolumeStream volumer(i2s);
EncodedAudioStream decoder(&volumer, new MP3DecoderHelix());
File audioFile;
// StreamCopy copier(decoder, audioFile, COPIER_BUFFER_SIZE);
StreamCopy copier;

Ewma volume_smoother(0.05); // 0.1 : less smoothing // 0.01 : More smoothing - less prone to noise, but slower to detect changes
Ewma battery_smoother(0.1); // 0.1 : less smoothing // 0.01 : More smoothing - less prone to noise, but slower to detect changes

int status = is_menu;

Button2 button_home;
Button2 button_left;
Button2 button_right;
Button2 button_play;

String currentpath = "";

int currentstory = 0;
int totalstories = 0;

String stories[MAXSTORIES];

int volume = 0; // current volume
int lastVolume = 0;

float battery = 0; // battery level

int output = HEADPHONE;
int lastOutput = HEADPHONE;

bool led = true; // builtin led

void setup()
{
  // Alume la led à l'allumage
  pinMode(LED_BUILTIN, OUTPUT);
  digitalWrite(LED_BUILTIN, HIGH);

  if (DEBUG)
  {
    // initialization de la liaisoon série, attente max 2 secondes pour cela
    int count = 2000;
    while (!Serial && count--)
    {
      delay(1);
    }
  }
  Serial.begin(115200);

  // delay(100);
  Serial.println("*************** Story Box start V3.2 ****************");
  // delay(100);

  // logger

  AudioLogger::instance().begin(Serial, AudioLogger::Warning);
  // AudioLogger::instance().begin(Serial, AudioLogger::Info); // use this for more logs

  SDFSConfig sdconfig;
  sdconfig.setCSPin(SDCARD_CS_PIN);
  SDFS.setConfig(sdconfig);

  if (!SDFS.begin())
  {
    blink(5);
    Serial.printf("Init sd failed\n");
    // SDFS.errorHalt();
  }

  // i2s
  auto config = i2s.defaultConfig(TX_MODE);
  config.pin_bck = I2S_BCK;
  config.pin_ws = I2S_WS;
  config.pin_data = I2S_DATA;
  i2s.begin(config);

  // setup I2S based on sampling rate provided by decoder
  // decoder.setNotifyAudioChange(i2s);
  // decoder.addNotifyAudioChange(i2s);
  copier.setSynchAudioInfo(true);

  decoder.begin();

  // copier buffer size
  copier.resize(COPIER_BUFFER_SIZE);

  // volume
  // auto volume_config = volumer.defaultConfig();
  // volume_config.allow_boost = true; // this allows volume > 1.0 be careful with this setting
  volumer.begin(config); // we need to provide the bits_per_sample and channels
  // volumer.begin(volume_config);
  volumer.setVolume(0.1);

  // delay(100);

  // Gestion des buttons : il vaut mieux lire une première fois chaque entrée pour éviter les fausses lectures
  pinMode(BUTTON_LEFT_PIN, INPUT_PULLUP);
  pinMode(BUTTON_RIGHT_PIN, INPUT_PULLUP);
  pinMode(BUTTON_HOME_PIN, INPUT_PULLUP);
  pinMode(BUTTON_PLAY_PIN, INPUT_PULLUP);

  digitalRead(BUTTON_LEFT_PIN);
  digitalRead(BUTTON_RIGHT_PIN);
  digitalRead(BUTTON_HOME_PIN);
  digitalRead(BUTTON_PLAY_PIN);

  button_left.begin(BUTTON_LEFT_PIN);
  button_left.setTapHandler(handleTapLeft);

  button_right.begin(BUTTON_RIGHT_PIN);
  button_right.setTapHandler(handleTapRight);

  button_home.begin(BUTTON_HOME_PIN);
  button_home.setTapHandler(handleTapHome);

  button_play.begin(BUTTON_PLAY_PIN);
  button_play.setTapHandler(handleTapPlay);

  // check battery level and warns if needed

  handleBattery();

  if (battery < LOW_VOLTAGE_WARNING)
  {
    play("/lowbattery.mp3");
  }
  else
  {
    play("/intro.mp3");
  }

  handleDirectoryChange();
  digitalWrite(LED_BUILTIN, LOW);
  debug();
}

void blink(int times)
{
  // delay(500);
  for (int i = 0; i < times; i++)
  {
    digitalWrite(LED_BUILTIN, HIGH);
    delay(200);
    digitalWrite(LED_BUILTIN, LOW);
    delay(200);
  }
  // delay(500);
}

void play(String filename)
{
  audioFile = SDFS.open(filename, "r");
  copier.begin(decoder, audioFile);
  Serial.print("Play start ");
  Serial.println(filename);
}

void playmenu()
{
  status = is_menu;
  String menu = "/menu.mp3";
  play(currentpath + '/' + stories[currentstory] + menu);
}

// currentpath
// currentstory = 0 .. int
// totalstories = int
// liste des dossier dans le dossier actuel -> tableau -> stories

void debug()
{
  if (DEBUG)
  {
    Serial.print("Current path : ");
    Serial.println(currentpath);
    Serial.print("totalstories : ");
    Serial.println(totalstories);
    Serial.print("Current story : ");
    Serial.println(currentstory);
    Serial.println("Stories found : ");
    for (int i = 0; i < totalstories; i++)
    {
      Serial.print("- ");
      Serial.println(stories[i]);
    }
    if (status == is_play)
    {
      Serial.println("*** playing ****");
    }

    if (status == is_menu)
    {
      Serial.println("*** on menu ****");
    }

    if (status == is_pause)
    {
      Serial.println("*** paused ****");
    }

    handleTemperature();
    handleBattery();
    handleJack();

    if (output == HEADPHONE)
    {
      Serial.println("Ouptut : headphone");
    }

    if (output == SPEAKER)
    {
      Serial.println("Ouptut : speaker");
    }

    Serial.print("Volume : ");
    Serial.println(volume);

    Serial.println("-----------------");
  }
}

void handleDirectoryChange()
{
  totalstories = 0;
  Dir dir = SDFS.openDir(currentpath);
  while (dir.next())
  {
    if (dir.isDirectory())
    {
      stories[totalstories] = dir.fileName();
      totalstories++;
    }
  }
}

void handleTapLeft(Button2 &b)
{
  Serial.println("-----------------");
  Serial.println("button left pressed");
  Serial.println("-----------------");

  currentstory--;
  if (currentstory < 0)
  {
    currentstory = totalstories - 1;
  }
  int i = 0;

  playmenu();
  debug();
}

void handleTapRight(Button2 &b)
{
  Serial.println("-----------------");
  Serial.println("button right pressed");
  Serial.println("-----------------");

  currentstory++;
  if (currentstory >= totalstories)
  {
    currentstory = 0;
  }
  playmenu();
  debug();
}

void handleTapHome(Button2 &b)
{
  Serial.println("-----------------");
  Serial.println("button home pressed");
  Serial.println("-----------------");

  currentpath = "";
  handleDirectoryChange();
  debug();
}

void handleTapPlay(Button2 &b)
{
  Serial.println("-----------------");
  Serial.println("button play pressed");
  Serial.println("-----------------");

  // si on est en train de lire une histoire, on la pause

  if (status == is_play)
  {
    status = is_pause;
    debug();
    return;
  }
  // si on est en pause, on lit
  if (status == is_pause)
  {
    status = is_play;
    debug();
    return;
  }

  // si on est dans un dossier avec des sous dossier, on rentre dedans et on joue le intro.mp3 + le menu.mp3 du premier sous dossier
  // on change le currentpath

  // si pas de sous dossier, on joue l'histoire

  play(currentpath + '/' + stories[currentstory] + "/story.mp3");
  status = is_play;

  debug();
}

void handleBattery()
{
  /*
  4.2 volts 100%
  4.1 about 90%
  4.0 about 80%
  3.9 about 60%
  3.8 about 40%
  3.7 about 20%
  3.6 empty for practical purposes.

or

4.2V - 100%; 4V - 80%; 3.8V - 60%; 3.6V - 40%; 3.4V - 20%


  */

  float vsys = float(analogRead(29)) * 3.0 * 3.3 / 1024;
  Serial.print("vsys : ");
  Serial.println(vsys);

  // float battery_raw = battery_smoother.filter(analogRead(BATTERY_ADC_PIN));
  battery = battery_smoother.filter(analogRead(BATTERY_ADC_PIN)) * VOLTAGE_DIVIDER_FACTOR * 3.3 / 1024 + VOLTAGE_DROP; // the VOLTAGE_DROP is to acknowledge the voltage drop from the schotky diode
  Serial.print("battery : ");
  Serial.println(battery);
}

void handleTemperature()
{
  int temperature = analogReadTemp();
  Serial.print("Temperature : ");
  Serial.println(temperature);
}

/**
 * Reads the jack analog input 10 times, takes the highest signal,
 * if < JACK_DETECTION_LEVEL it means a jack is connected, reduce max volume for headphones
 * If > JACK_DETECTION_LEVEL it means a jack is not connected, we are in speaker mode, don't reduce volume
 *
 */
void handleJack()
{
  int max = 0;
  for (int i = 0; i < 10; i++)
  {
    int read = analogRead(JACK_PIN);
    if (read > max)
    {
      max = read;
    }
  }

  // Serial.print("Jack max : ");
  // Serial.println(max);

  if (max > JACK_DETECTION_LEVEL)
  {
    output = SPEAKER;
  }
  else
  {
    output = HEADPHONE;
  }
}

void handleVolume()
{
  volume = volume_smoother.filter(analogRead(VOLUME_PIN));
  volume = map(volume, 0, 1024, 0, VOLUME_STEPS);

  if (volume != lastVolume || output != lastOutput)
  {
    lastVolume = volume;
    lastOutput = output;

    if (output == HEADPHONE)
    {
      volumer.setVolume(float(map(volume, 0, VOLUME_STEPS, 0, MAX_HEADPHONE_VOLUME)) / 1024);
    }

    if (output == SPEAKER)
    {
      volumer.setVolume(float(map(volume, 0, VOLUME_STEPS, 0, MAX_SPEAKER_VOLUME)) / 1024);
    }

    Serial.print("Volume : ");
    Serial.println(volume);
  }
}

void loop()
{

  // fait clignoter la led dans la boucle pour voir que le code tourne bien
  led = !led;
  if (led)
  {
    digitalWrite(LED_BUILTIN, HIGH);
  }
  else
  {
    digitalWrite(LED_BUILTIN, LOW);
  }

  // gestion des boutons
  button_left.loop();
  button_right.loop();
  button_home.loop();
  button_play.loop();

  // gestion du bouton de volume
  handleVolume();

  // gestion de l'état de la prise jack
  handleJack();

  // boucle de copie du son
  if (status == is_play || status == is_menu)
  {
    copier.copy();
  }
  else
  {
    delay(20);
  }
}

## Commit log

2024-08-19 dernière version de la pcb + schéma
    [storybox.kicad_pcb, storybox.kicad_sch]
2024-08-19 dernière version du code arduino
2025-04-22 Update README.md with bom
